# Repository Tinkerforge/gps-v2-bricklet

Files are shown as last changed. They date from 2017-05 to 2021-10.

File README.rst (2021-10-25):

GPS Bricklet 2.0
================

This repository contains the firmware source code and the hardware design
files. The documentation generator configs can be found at
https://github.com/Tinkerforge/generators

Repository Content
------------------

software/:
 * examples/: Examples for all supported languages
 * build/: Compiled files
 * src/: Source code of firmware
 * Makefile: Makefile to build project

hardware/:
 * Contains KiCad project files and additionally schematics as PDF

datasheets/:
 * Contains datasheets for sensors and complex ICs that are used

Hardware
--------

The hardware is designed with the open source EDA Suite KiCad
(http://www.kicad.org). Before you are able to open the files,
you have to install the Tinkerforge kicad-libraries
(https://github.com/Tinkerforge/kicad-libraries). You can either clone
them directly in hardware/ or clone them in a separate folder and
symlink them into hardware/
(ln -s kicad_path/kicad-libraries project_path/hardware). After that you
can open the .pro file in hardware/ with KiCad and from there view and
modify the schematics and the PCB layout.

Software
--------

If you want to do your own Brick/Bricklet firmware development we highly
recommend that you use our build environment setup script and read the
tutorial (https://www.tinkerforge.com/en/doc/Tutorials/Tutorial_Build_Environment/Tutorial.html).

To compile the C code we recommend you to install the newest GNU Arm Embedded
Toolchain (https://launchpad.net/gcc-arm-embedded/+download).
You also need to install bricklib2 (https://github.com/Tinkerforge/bricklib2).

You can either clone it directly in software/src/ or clone it in a
separate folder and symlink it into software/src/
(ln -s bricklib_path/bricklib2 project_path/software/src/). Finally make sure to
have CMake installed (http://www.cmake.org/cmake/resources/software.html).

After that you can build the firmware by invoking make in software/.
The firmware (.zbin) can then be found in software/build/ and uploaded
with brickv (click button "Flashing" on start screen).

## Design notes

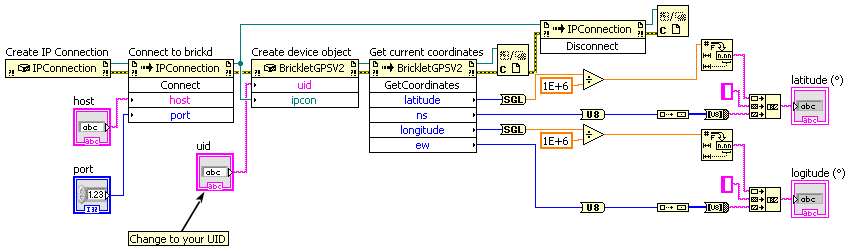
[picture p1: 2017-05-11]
software/examples/labview/Example Simple.vi.png

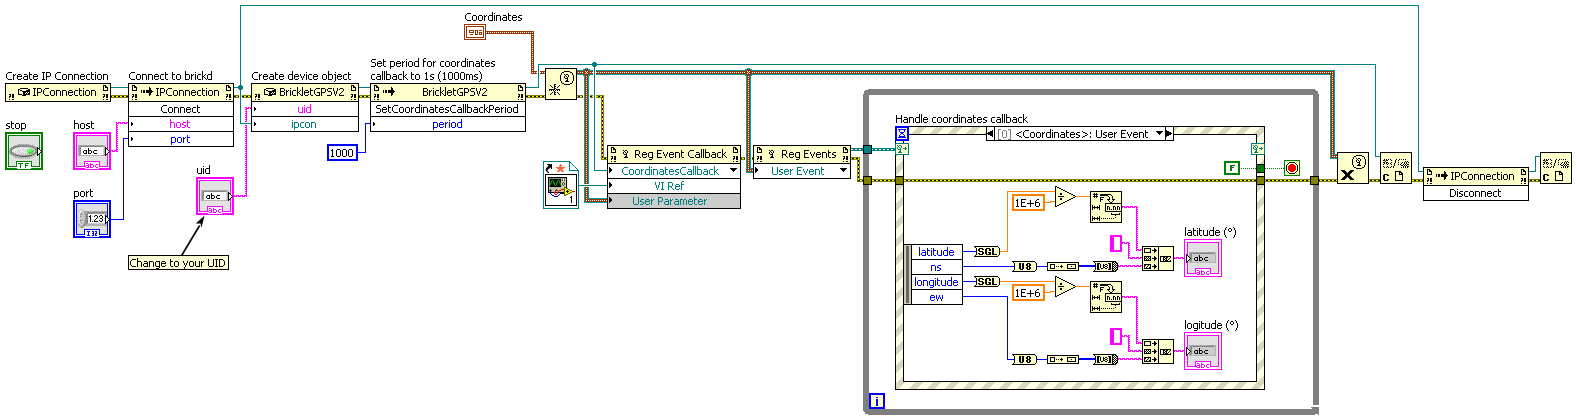
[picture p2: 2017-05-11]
software/examples/labview/Example Callback.vi.png

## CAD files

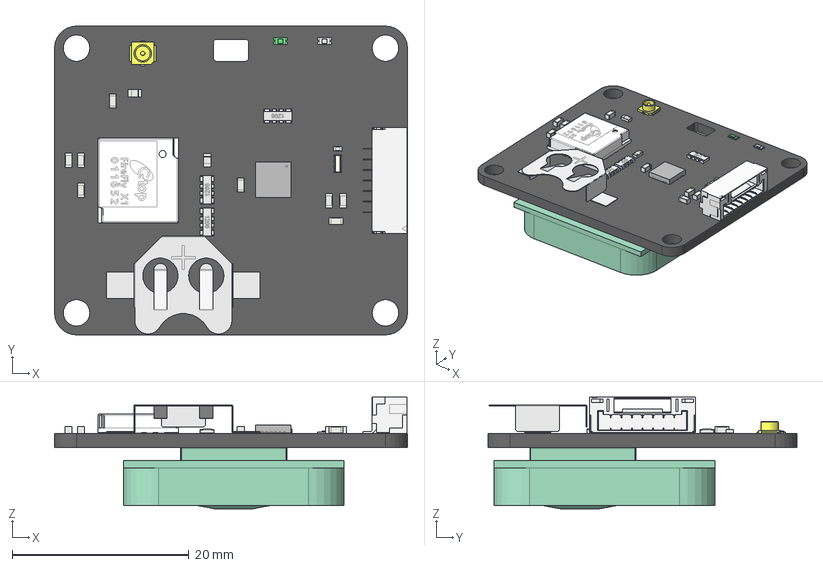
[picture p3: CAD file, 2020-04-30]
hardware/gps-v2.1.FCStd
40.0 x 35.0 x 12.7 mm
Pcb
P101_BrickletConn_7pin_5874F493
R_4x0603
D102_Fusion_5809374E
U101_QFN-24_4x4mm_Pitch0.5mm_5806613C
RP101__5806D9E0
RP102__5806D9F0
D_0603_blue
C101_C_0603_5943B8CD
C102_C_0603_5943B8D6
C103_C_0603_5943B8DF
C104_C_0603_5943B8E8
C105_C_0603_5943B8F1
C106_C_0603_5943B8FA
C107_C_0603_5943B903
FB101_C_0603_5943B90C
R102_R_0603_5943B915
BT101_Battery_Retainer_58093CEE
U102_FireFly_X1_58066159
P104_U-FL_5806DF75
C1_C_0402_5CAAF6C5
RP2_Cut_5CAAF6D5
L101_R_0603_5CAAFCC3
REF_FT-GPS-001_594D0BBF

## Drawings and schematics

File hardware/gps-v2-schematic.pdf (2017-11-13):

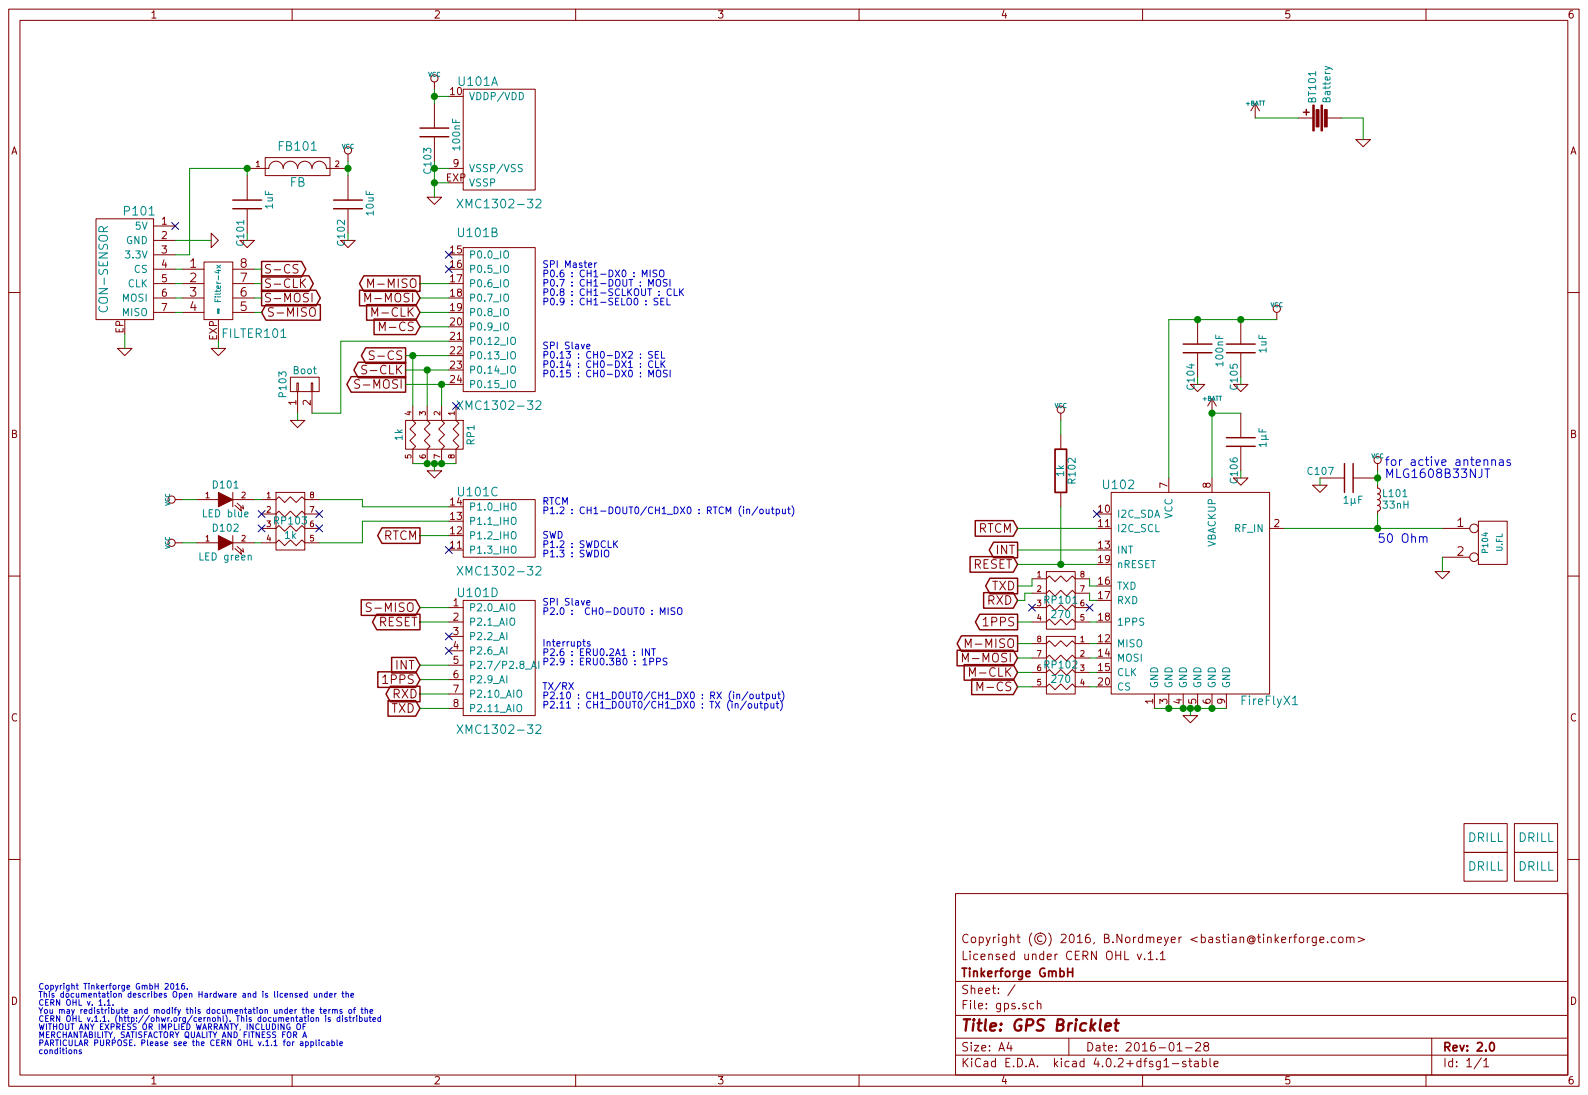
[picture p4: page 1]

SPI Master P0.6 : CH1-DX0 : MISO
P0.7 : CH1-DOUT : MOSI P0.8 : CH1-SCLKOUT : CLK
P0.9 : CH1-SELO0 : SEL

SPI Slave P0.13 : CH0-DX2 : SEL P0.14 : CH0-DX1 : CLK

P2.10 : CH1_DOUT0/CH1_DX0 : RX (in/output) P2.11 : CH1_DOUT0/CH1_DX0 : TX (in/output) RTCM
P1.2 : CH1-DOUT0/CH1_DX0 : RTCM (in/output) SPI Slave P2.0 : CH0-DOUT0 : MISO

Licensed under CERN OHL v.1.1 Copyright (©) 2016, B.Nordmeyer <bastian@tinkerforge.com>

File: gps.sch Sheet: / Tinkerforge GmbH

Copyright Tinkerforge GmbH 2016. This documentation describes Open Hardware and is licensed under the CERN OHL v. 1.1. You may redistribute and modify this documentation under the terms of the CERN OHL v.1.1. (http://ohwr.org/cernohl). This documentation is distributed WITHOUT ANY EXPRESS OR IMPLIED WARRANTY, INCLUDING OF MERCHANTABILITY, SATISFACTORY QUALITY AND FITNESS FOR A

Id: 1/1 Title: GPS Bricklet

PARTICULAR PURPOSE. Please see the CERN OHL v.1.1 for applicable

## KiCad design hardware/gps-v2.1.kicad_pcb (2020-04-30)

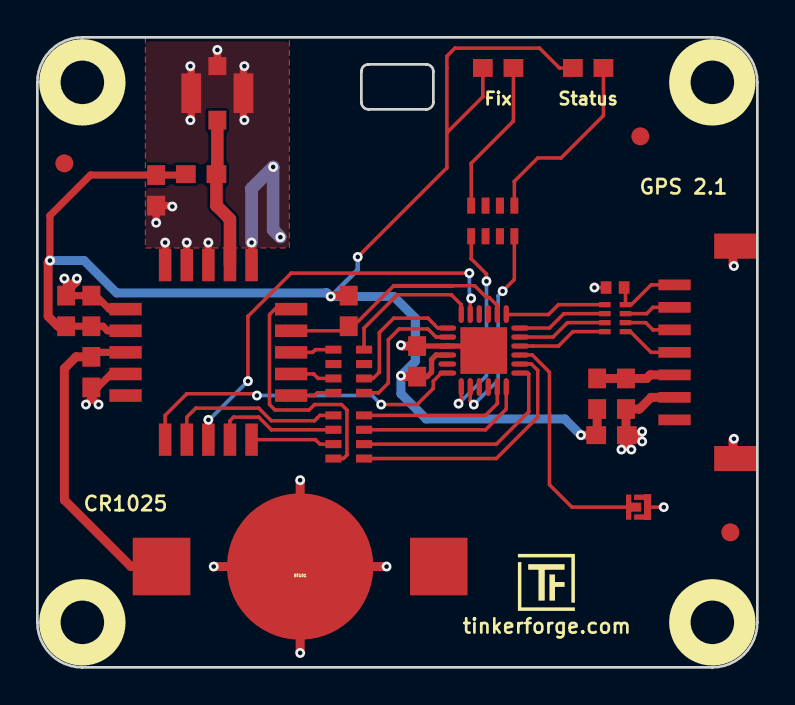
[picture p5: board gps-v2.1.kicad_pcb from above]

Board: 2 copper layers, 40.0 x 35.0 mm, 32 parts (2 on the bottom side), 35 nets.

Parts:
BT101: Battery; BATTERY_HOLDER_BK870
C1: 220pF; C0402F
C101, C105: 1uF; C0603E
C102: 10uF; C0603E
C103, C104: 100nF; C0603E
C106, C107: 1µF; C0603E
D101: LED blue; D0603E
D102: LED green; D0603E
FB101: FB; C0603E
Fiducial_Mark: VAL**; Fiducial_Mark
Fiducial_Mark#2, Fiducial_Mark#3: VAL**; Fiducial_Mark
L101: 33nH; R0603E
P101: CON-SENSOR; CON-SENSOR2
P103: Boot; SolderJumper
P104: U.FL; U.FL-CON
R102: 1k; R0603E
RP2: 82; 4X0402
RP101, RP102: 270; 0603X4
RP103: 1k; 0603X4
U101: XMC1302-32; QFN24-4x4mm-0.5mm
U102: FireFlyX1
U103, U104, U105, U106: DRILL; DRILL_NP
VAL: WEEE_7mm
VAL#2: CE_5mm

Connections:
1PPS: RP101.4, U101.6
GND: BT101.2, C1.2, C101.1, C102.1, C103.1, C104.1, C105.1, C106.1, C107.1, P101.2, P101.EP, P103.1, P104.2, U101.9, U101.EXP, U102.1, U102.3, U102.4, U102.5, U102.6, U102.9
INT: U101.5, U102.13
M-CLK: RP102.6, U101.19
M-CS: RP102.5, U101.20
M-MISO: RP102.8, U101.17
M-MOSI: RP102.7, U101.18
unnamed: C1.1, P101.7, RP2.4
unnamed: C101.2, FB101.2, P101.3
unnamed: D101.2, RP103.1
unnamed: D102.2, RP103.4
unnamed: L101.2, P104.1, U102.2
unnamed: P101.4, RP2.1
unnamed: P101.5, RP2.2
unnamed: P101.6, RP2.3
unnamed: P103.2, U101.21
unnamed: RP101.5, U102.18
unnamed: RP101.7, U102.17
unnamed: RP101.8, U102.16
unnamed: RP102.1, U102.12
unnamed: RP102.2, U102.14
unnamed: RP102.3, U102.15
unnamed: RP102.4, U102.20
unnamed: RP103.5, U101.13
unnamed: RP103.8, U101.14
RESET: R102.2, U101.2, U102.19
RTCM: U101.12, U102.11
RXD: RP101.2, U101.7
S-CLK: RP2.7, U101.23
S-CS: RP2.8, U101.22
S-MISO: RP2.5, U101.1
S-MOSI: RP2.6, U101.24
TXD: RP101.1, U101.8
VBat: BT101.1, C106.2, U102.8
VCC: C102.2, C103.2, C104.2, C105.2, C107.2, D101.1, D102.1, FB101.1, L101.1, R102.1, U101.10, U102.7

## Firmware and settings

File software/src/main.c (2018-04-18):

/* gps-v2-bricklet
 * Copyright (C) 2016 Olaf Lüke <olaf@tinkerforge.com>
 *
 * main.c: Initialization for GPS Bricklet 2.0
 *
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
 * You should have received a copy of the GNU Lesser General Public
 * License along with this library; if not, write to the
 * Free Software Foundation, Inc., 59 Temple Place - Suite 330,
 * Boston, MA 02111-1307, USA.
 */

#include <stdio.h>
#include <stdbool.h>

#include "xmc_scu.h"
#include "xmc_spi.h"
#include "xmc_gpio.h"
#include "configs/config.h"

#include "bricklib2/bootloader/bootloader.h"
#include "bricklib2/utility/communication_callback.h"
#include "bricklib2/logging/logging.h"
#include "communication.h"
#include "firefly_x1.h"

#define SYSTEM_TIMER_FREQUENCY 1000 // Use 1 kHz system timer

FireFlyX1 firefly_x1;

int main(void) {
	logging_init();
	logd("Start GPS V2 Bricklet\n\r");

	communication_callback_init();
	firefly_x1_init(&firefly_x1);

	while(true) {
		bootloader_tick();
		firefly_x1_tick(&firefly_x1);
		communication_tick();
	}

}

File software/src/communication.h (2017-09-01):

/* gps-v2-bricklet
 * Copyright (C) 2016 Olaf Lüke <olaf@tinkerforge.com>
 *
 * communication.h: TFP protocol message handling
 *
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
 * You should have received a copy of the GNU Lesser General Public
 * License along with this library; if not, write to the
 * Free Software Foundation, Inc., 59 Temple Place - Suite 330,
 * Boston, MA 02111-1307, USA.
 */

#ifndef COMMUNICATION_H
#define COMMUNICATION_H

#include <stdint.h>
#include <stdbool.h>

#include "bricklib2/bootloader/bootloader.h"

// Default functions
BootloaderHandleMessageResponse handle_message(const void *data, void *response);
void communication_tick(void);
void communication_init(void);

// Constants
#define GPS_V2_RESTART_TYPE_HOT_START 0
#define GPS_V2_RESTART_TYPE_WARM_START 1
#define GPS_V2_RESTART_TYPE_COLD_START 2
#define GPS_V2_RESTART_TYPE_FACTORY_RESET 3

#define GPS_V2_SATELLITE_SYSTEM_GPS 0
#define GPS_V2_SATELLITE_SYSTEM_GLONASS 1
#define GPS_V2_SATELLITE_SYSTEM_GALILEO 2

#define GPS_V2_FIX_NO_FIX 1
#define GPS_V2_FIX_2D_FIX 2
#define GPS_V2_FIX_3D_FIX 3

#define GPS_V2_FIX_LED_CONFIG_OFF 0
#define GPS_V2_FIX_LED_CONFIG_ON 1
#define GPS_V2_FIX_LED_CONFIG_SHOW_HEARTBEAT 2
#define GPS_V2_FIX_LED_CONFIG_SHOW_FIX 3
#define GPS_V2_FIX_LED_CONFIG_SHOW_PPS 4

#define GPS_V2_SBAS_ENABLED 0
#define GPS_V2_SBAS_DISABLED 1

// Function and callback IDs and structs
#define FID_GET_COORDINATES 1
#define FID_GET_STATUS 2
#define FID_GET_ALTITUDE 3
#define FID_GET_MOTION 4
#define FID_GET_DATE_TIME 5
#define FID_RESTART 6
#define FID_GET_SATELLITE_SYSTEM_STATUS_LOW_LEVEL 7
#define FID_GET_SATELLITE_STATUS 8
#define FID_SET_FIX_LED_CONFIG 9
#define FID_GET_FIX_LED_CONFIG 10
#define FID_SET_COORDINATES_CALLBACK_PERIOD 11
#define FID_GET_COORDINATES_CALLBACK_PERIOD 12
#define FID_SET_STATUS_CALLBACK_PERIOD 13
#define FID_GET_STATUS_CALLBACK_PERIOD 14
#define FID_SET_ALTITUDE_CALLBACK_PERIOD 15
#define FID_GET_ALTITUDE_CALLBACK_PERIOD 16
#define FID_SET_MOTION_CALLBACK_PERIOD 17
#define FID_GET_MOTION_CALLBACK_PERIOD 18
#define FID_SET_DATE_TIME_CALLBACK_PERIOD 19
#define FID_GET_DATE_TIME_CALLBACK_PERIOD 20
#define FID_SET_SBAS_CONFIG 27
#define FID_GET_SBAS_CONFIG 28

#define FID_CALLBACK_PULSE_PER_SECOND 21
#define FID_CALLBACK_COORDINATES 22
#define FID_CALLBACK_STATUS 23
#define FID_CALLBACK_ALTITUDE 24
#define FID_CALLBACK_MOTION 25
#define FID_CALLBACK_DATE_TIME 26

typedef struct {
	TFPMessageHeader header;
} __attribute__((__packed__)) GetCoordinates;

typedef struct {
	TFPMessageHeader header;
	uint32_t latitude;
	char ns;
	uint32_t longitude;
	char ew;
} __attribute__((__packed__)) GetCoordinates_Response;

typedef struct {
	TFPMessageHeader header;
} __attribute__((__packed__)) GetStatus;

typedef struct {
	TFPMessageHeader header;
	bool has_fix;
	uint8_t satellites_view;
} __attribute__((__packed__)) GetStatus_Response;

typedef struct {
	TFPMessageHeader header;
} __attribute__((__packed__)) GetAltitude;

typedef struct {
	TFPMessageHeader header;
	int32_t altitude;
	int32_t geoidal_separation;
} __attribute__((__packed__)) GetAltitude_Response;

typedef struct {
	TFPMessageHeader header;
} __attribute__((__packed__)) GetMotion;

typedef struct {
	TFPMessageHeader header;
	uint32_t course;
	uint32_t speed;
} __attribute__((__packed__)) GetMotion_Response;

typedef struct {
	TFPMessageHeader header;
} __attribute__((__packed__)) GetDateTime;

typedef struct {
	TFPMessageHeader header;
	uint32_t date;
	uint32_t time;
} __attribute__((__packed__)) GetDateTime_Response;

typedef struct {
	TFPMessageHeader header;
	uint8_t restart_type;
} __attribute__((__packed__)) Restart;

typedef struct {
	TFPMessageHeader header;
	uint8_t satellite_system;
} __attribute__((__packed__)) GetSatelliteSystemStatusLowLevel;

typedef struct {
	TFPMessageHeader header;
	uint8_t satellite_numbers_length;
	uint8_t satellite_numbers_data[12];
	uint8_t fix;
	uint16_t pdop;
	uint16_t hdop;
	uint16_t vdop;
} __attribute__((__packed__)) GetSatelliteSystemStatusLowLevel_Response;

typedef struct {
	TFPMessageHeader header;
	uint8_t satellite_system;
	uint8_t satellite_number;
} __attribute__((__packed__)) GetSatelliteStatus;

typedef struct {
	TFPMessageHeader header;
	int16_t elevation;
	int16_t azimuth;
	int16_t snr;
} __attribute__((__packed__)) GetSatelliteStatus_Response;

typedef struct {
	TFPMessageHeader header;
	uint8_t config;
} __attribute__((__packed__)) SetFixLEDConfig;

typedef struct {
	TFPMessageHeader header;
} __attribute__((__packed__)) GetFixLEDConfig;

typedef struct {
	TFPMessageHeader header;
	uint8_t config;
} __attribute__((__packed__)) GetFixLEDConfig_Response;

typedef struct {
	TFPMessageHeader header;
	uint32_t period;
} __attribute__((__packed__)) SetCoordinatesCallbackPeriod;

typedef struct {
	TFPMessageHeader header;
} __attribute__((__packed__)) GetCoordinatesCallbackPeriod;

typedef struct {
	TFPMessageHeader header;
	uint32_t period;
} __attribute__((__packed__)) GetCoordinatesCallbackPeriod_Response;

typedef struct {
	TFPMessageHeader header;
	uint32_t period;
} __attribute__((__packed__)) SetStatusCallbackPeriod;

typedef struct {
	TFPMessageHeader header;
} __attribute__((__packed__)) GetStatusCallbackPeriod;

typedef struct {
	TFPMessageHeader header;
	uint32_t period;
} __attribute__((__packed__)) GetStatusCallbackPeriod_Response;

typedef struct {
	TFPMessageHeader header;
	uint32_t period;
} __attribute__((__packed__)) SetAltitudeCallbackPeriod;

typedef struct {
	TFPMessageHeader header;
} __attribute__((__packed__)) GetAltitudeCallbackPeriod;

typedef struct {
	TFPMessageHeader header;
	uint32_t period;
} __attribute__((__packed__)) GetAltitudeCallbackPeriod_Response;

typedef struct {
	TFPMessageHeader header;
	uint32_t period;
} __attribute__((__packed__)) SetMotionCallbackPeriod;

typedef struct {
	TFPMessageHeader header;
} __attribute__((__packed__)) GetMotionCallbackPeriod;

typedef struct {
	TFPMessageHeader header;
	uint32_t period;
} __attribute__((__packed__)) GetMotionCallbackPeriod_Response;

typedef struct {
	TFPMessageHeader header;
	uint32_t period;
} __attribute__((__packed__)) SetDateTimeCallbackPeriod;

typedef struct {
	TFPMessageHeader header;
} __attribute__((__packed__)) GetDateTimeCallbackPeriod;

typedef struct {
	TFPMessageHeader header;
	uint32_t period;
} __attribute__((__packed__)) GetDateTimeCallbackPeriod_Response;

typedef struct {
	TFPMessageHeader header;
} __attribute__((__packed__)) PulsePerSecond_Callback;

typedef struct {
	TFPMessageHeader header;
	uint32_t latitude;
	char ns;
	uint32_t longitude;
	char ew;
} __attribute__((__packed__)) Coordinates_Callback;

typedef struct {
	TFPMessageHeader header;
	bool has_fix;
	uint8_t satellites_view;
} __attribute__((__packed__)) Status_Callback;

typedef struct {
	TFPMessageHeader header;
	int32_t altitude;
	int32_t geoidal_separation;
} __attribute__((__packed__)) Altitude_Callback;
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

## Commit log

2016-09-02 Add initial firmware with bootloader support
    [gps.kicad_pcb, gps.sch]
2016-09-06 Add system timer
2016-09-15 Use four DMA channels (2x bootloader SPI and 2x firmware SPI)
2016-09-15 Add FireFly X1 driver stub
2016-09-15 Add FireFly X1 driver config
2016-10-19 adding hardware prototype for new version with co-processor
    [gps.kicad_pcb, gps.sch]
2016-10-19 change battery holder to version for cr-1025
    [gps.kicad_pcb, gps.sch]
2016-11-10 Change default debug pin to boot pin
2016-11-10 SPI config not needed anymore
2016-11-11 remove boot description
    [gps.kicad_pcb]
2016-11-11 Add ringbuffer for incoming data, parse incoming data into structs that hold all of current data
2016-11-14 Add custom cmake config
    [cmake_config_custom.txt]
2016-11-14 Add correct flash origin and size to cmake configs
    [cmake_config_custom.txt]
2016-11-17 System timer initialization now done during startup, before main is called
2016-12-08 Use 32kb flash size
    [cmake_config_custom.txt]
2016-12-08 Add missing custom bootloader configuration
    [config_custom_bootloader.h]
2016-12-08 Add reset function handling
    [firefly_x1.c]
2016-12-15 fix pin mapping
    [gps.kicad_pcb, gps.sch]
2016-12-15 Add fix LED configuration and logic
    [communication.c, communication.h, config_firefly_x1.h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]
2017-01-03 remove silkscreen areas around leds
    [gps.kicad_pcb]
2017-01-04 drc check, change reset pullup 10k->1k
    [gps.kicad_pcb, gps.sch]
2017-01-04 add fiducials
    [gps.kicad_pcb]
2017-01-10 change bricklet connector to 7pole JST GH
    [gps.kicad_pcb, gps.sch]
2017-01-10 fix grid origin
    [gps.kicad_pcb]
2017-01-12 change via size, add spi pulldowns for inputs
    [gps.kicad_pcb, gps.sch]
2017-01-18 ange serial resistor values
    [gps.kicad_pcb, gps.sch]
2017-01-19 Change MCU to 1302
    [cmake_config_custom.txt]
2017-01-31 slot for external antenna added
    [gps.kicad_pcb]
2017-03-07 Fix scale factors for altitude and height to give cm
    [communication.c]
2017-03-10 Make sure fix LED blinks if fix quality is 0
    [firefly_x1.c]
2017-03-10 Change fix LED to just be on or off to indicate fix
    Also add PPS mode for fix LED.
    [communication.c, communication.h, firefly_x1.c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]
2017-05-31 Report speed correctly as km/h instead of knots
    [communication.c, firefly_x1.c, firefly_x1.h]
2017-06-16 Add 3d information (tbc)
    [gps.kicad_pcb, gps.sch]
2017-06-23 Add 3d information (final)
    [gps.kicad_pcb]
2017-06-23 Add 3d model (*.FCStd and *.STEP)
    [gps.FCStd]
2017-07-12 add missing schematic
2017-08-31 Reset FireflyX1 if it doesn't talk to us anymore
    If we don't get an interrupt for a long time we first try to
    read from it without interrupt. If we don't get any data back we
    reset the IC.
    [firefly_x1.c, firefly_x1.h]
2017-09-01 Increase SPI speed to 200kHz
    200kHz is definitely fast enough to receive all data with 10Hz update rate
2017-09-06 Decrease baudrate to 100000 again
    This seems to be enough for the full 10Hz of data
2017-09-19 specify processor
    [gps.kicad_pcb, gps.sch]
2017-11-06 update u.fl footprint
    [gps.kicad_pcb]
2017-11-13 Fix schematic PDF: processor type was unspecified
2018-02-20 Cleanup KiCad libraries config
    Ensure LibDir=kicad-libraries and LibName1=tinkerforge.
    Remove special library.
2018-04-23 Reconfigure SBAS after cold-restart and factory-reset
    [firefly_x1.c]
2018-04-26 Handle different latitude, longitude and altitude resolutions correctly
    [communication.c]
2018-05-11 Rename files
    [gps-v2.FCStd, gps-v2.kicad_pcb, gps-v2.sch]
2018-12-14 go: Fix printf parameters.
2019-04-08 new filter design
    [gps-v2.1.kicad_pcb, gps-v2.1.sch]
2019-04-08 v2.1 ready for prototype
    [gps-v2.1.kicad_pcb, gps-v2.1.sch]
2019-06-13 Fix speed overflow at speeds >=214.74km/h
    [communication.c]
2019-08-22 c: Adapt to bindings changes
    [example_callback.c]
2019-11-14 Use correct scales for VDOP/PDOP calculation.
    [communication.c]
2019-11-18 change to version 2.1
    [gps-v2.1.kicad_pcb, gps-v2.1.sch, gps-v2.FCStd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]
2019-11-21 fix weee logo
    [gps-v2.1.kicad_pcb]
2019-11-27 add battery description
    [gps-v2.1.kicad_pcb]
2019-12-03 Avoid reset loop by setting last_data_time on reset
    Otherwise the last_data_time check would trigger again immediately
    without leaving the GPS module any time to respond.
    [firefly_x1.c]
2020-02-28 Add support for hardware version 2.1
    Hardware version 2.0 uses a FireFly X1 module that uses active-low logic
    for its interrupt pin.
    Hardware version 2.1 uses a XM1110 module that uses active-high logic
    for its interrupt pin.
    Assume active-high logic, but fall back to active-low if no interrupt
    occurs for 2 seconds.
2020-04-30 fix 3d data
    [gps-v2.1.FCStd, gps-v2.1.kicad_pcb]
2020-09-02 uc: Add example driver note.
2020-10-16 uc: Fix divisor type.
    [example_callback.c]
2021-10-25 Update KiCad link
    https://www.kicad.org/blog/2021/10/Avoid-links-to-former-kicad-domain/
2022-04-27 uc: Adapt to bindings changes
    [example_callback.c, example_simple.c]
